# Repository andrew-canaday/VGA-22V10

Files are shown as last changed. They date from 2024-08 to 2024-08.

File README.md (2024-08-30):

# 22V10 VGA Card

I had some ATF22V10C's lying around and tossed together a quick VGA card:

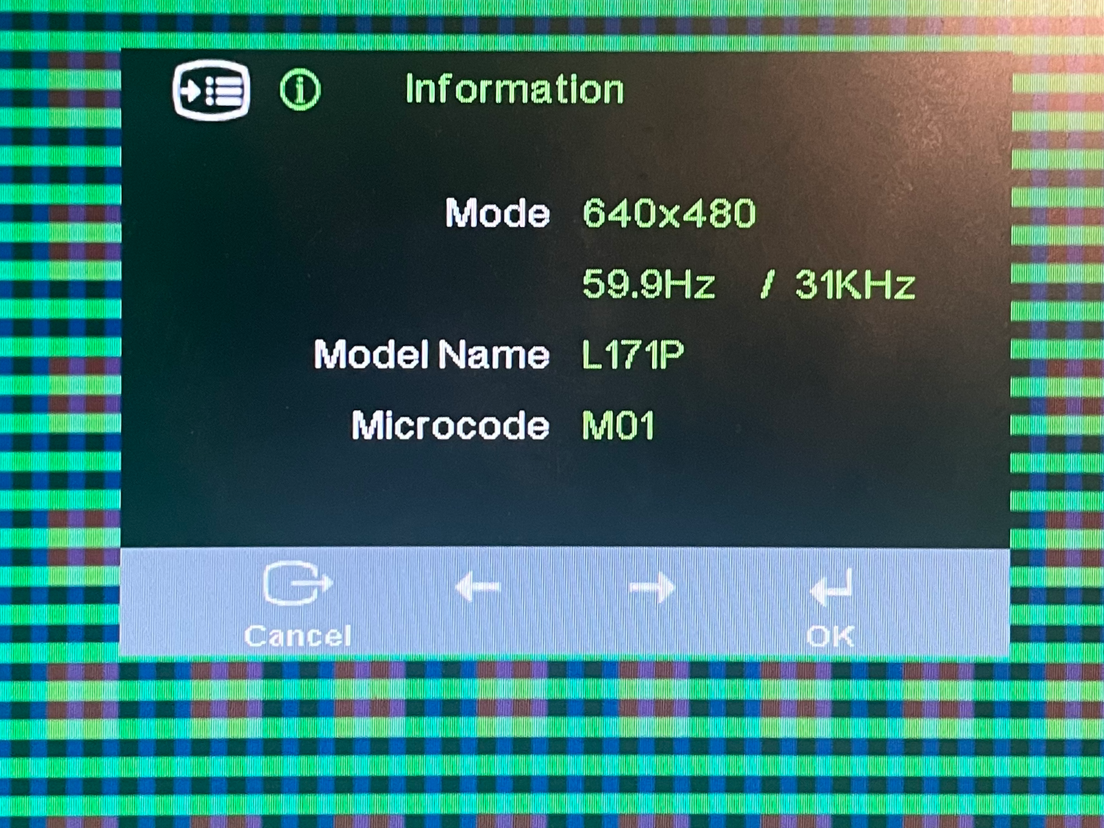
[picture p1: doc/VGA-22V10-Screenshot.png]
640x480 VGA Screenshot


### The Gist

> :information_source: **NOTE**: I happen to have a few **25.175MHz "Standard
> Clock" TCXO's and a pile of PLD's** lying around. Admittedly, this is a
> somewhat luxurious state of affairs. On the one hand, it makes the
> implementation significantly more straightforward. On the other, those aren't
> likely to be _super_ common "just lying around" parts for home hackers...

 - **Pixel Clock:** 25.175MHz
 - **Resolution:** 640x480
 - **Refresh:** 59.9Hz
 - 3 x ATF22V10C's
 - 1 x SN74**F**21 (Dual, 4-input, positive, `AND` — _mind your [Logic Family!](https://en.wikipedia.org/wiki/Logic_family#Monolithic_integrated_circuit_logic_families_compared)_)
 - **Inputs/Outputs:**
     - HSync + VSync,
     - "Visible" bool
     - VBlank flag
     - 20-bit pixel address output (10-bit H, 10-bit V)
     - analog RGB input

The POC is some pretty shoddy wire-pasta, but it works brilliantly...and is fun:

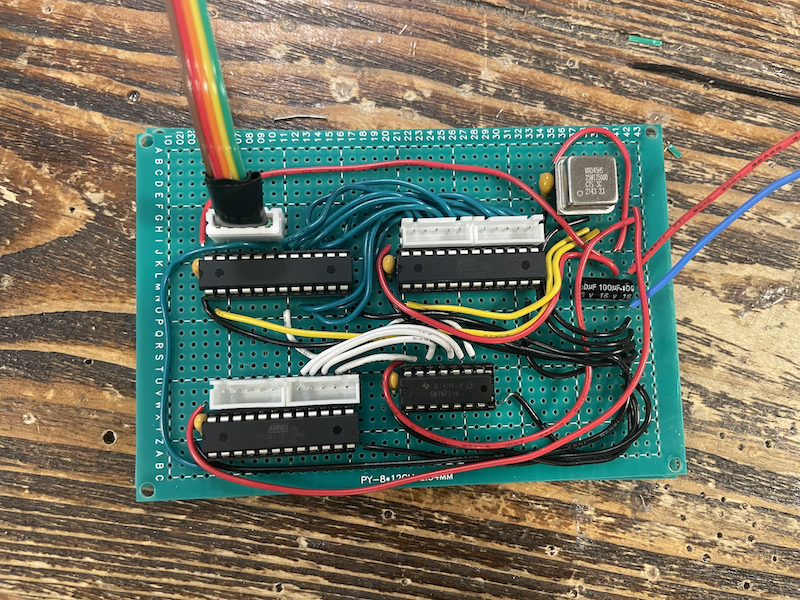
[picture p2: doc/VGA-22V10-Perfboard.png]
Gnarly, VGA, Perfboard Pasta


## Development

 - Written for GALasm (I use **[Galette](https://github.com/simon-frankau/galette)**)
 - Programmed with a T48 using **[Minipro](https://gitlab.com/DavidGriffith/minipro)**
 - For help: `make help`
 - To build and upload a unit: `UNIT=<my-file.pld> make clean compile upload`

### PLD Sources

> :information_source: **Schematic**: [PDF](./doc/schematic/22V10C-VGA-Card.pdf) / [SVG](./doc/schematic/22V10C-VGA-Card.svg)

 - `VGASync.pld` (ATF22V10C): HSync, VSync, Visible, and VBlank
 - `mod800.pld` (ATF22V10C): `% 800` counter
 - `mod525.pld` (ATF22V10C): `% 525` counter
 - Four-input `AND` on (`V32`, `V64`, `V128`, `V256`)

## Notes

 - I'm sure it's possible to reduce chip-count or make this more elegant — e.g. moving some of the sync
   counter logic from one IC into `VGASync.pld` / using some outputs in
   tri-state mode. This isn't the _optimal_ solution; it's just an easy,
   off-the-cuff, solution with proper timing.
 - Pinouts: _these are malleable!_ The current disposition is informed, more than
   anything else, by where the IC's happened to land on my breadboard.
   **Just mind your product terms!** (The number of product terms available to each
   macrocell varies by pin).
 - If you don't have "spare" 22V10's, you can replace the mod800/mod525 counters
   with synchronous counters or ripple-counters + latches. If you spec out your
   parts, mind your gate delays, and maybe add some additional product terms
   to your equations, you might be able to get away with a couple of 10+ bit
   ripple counters too!

## Misc

### Other PLD files

 - `counter.pld`: Generic 10-bit synchronous counter.
 - `eq-9-bit.pld`: Bit-wise comparison, 9-bits.

### Fun

#### Analog Switch Pixel Gate

Use the `Visible` output of `VGASync` to toggle 3 x SPST or SPDT switches for
red, green, and blue.

> :warning: **NOTE**: Watch your propagation delays!
>    
> If you use an analog switch that has a large ON/OFF (or Inhibit)
> propagation delay, relative to the pixel clock, you'll want to turn it
> on and off <i>early</i> to avoid offsetting your pixels horizontally.

#### Boolean Grids

Have some fast CMOS or TTL logic gates lying around? Taking the output from one
or more bits from `VAddr` and `HAddr`, passing them through some gates, and
`AND`'ing them with the `Visible` flag is a great way to check your pixel
alignment (this is how the grid pattern in the screenshot above was generated).

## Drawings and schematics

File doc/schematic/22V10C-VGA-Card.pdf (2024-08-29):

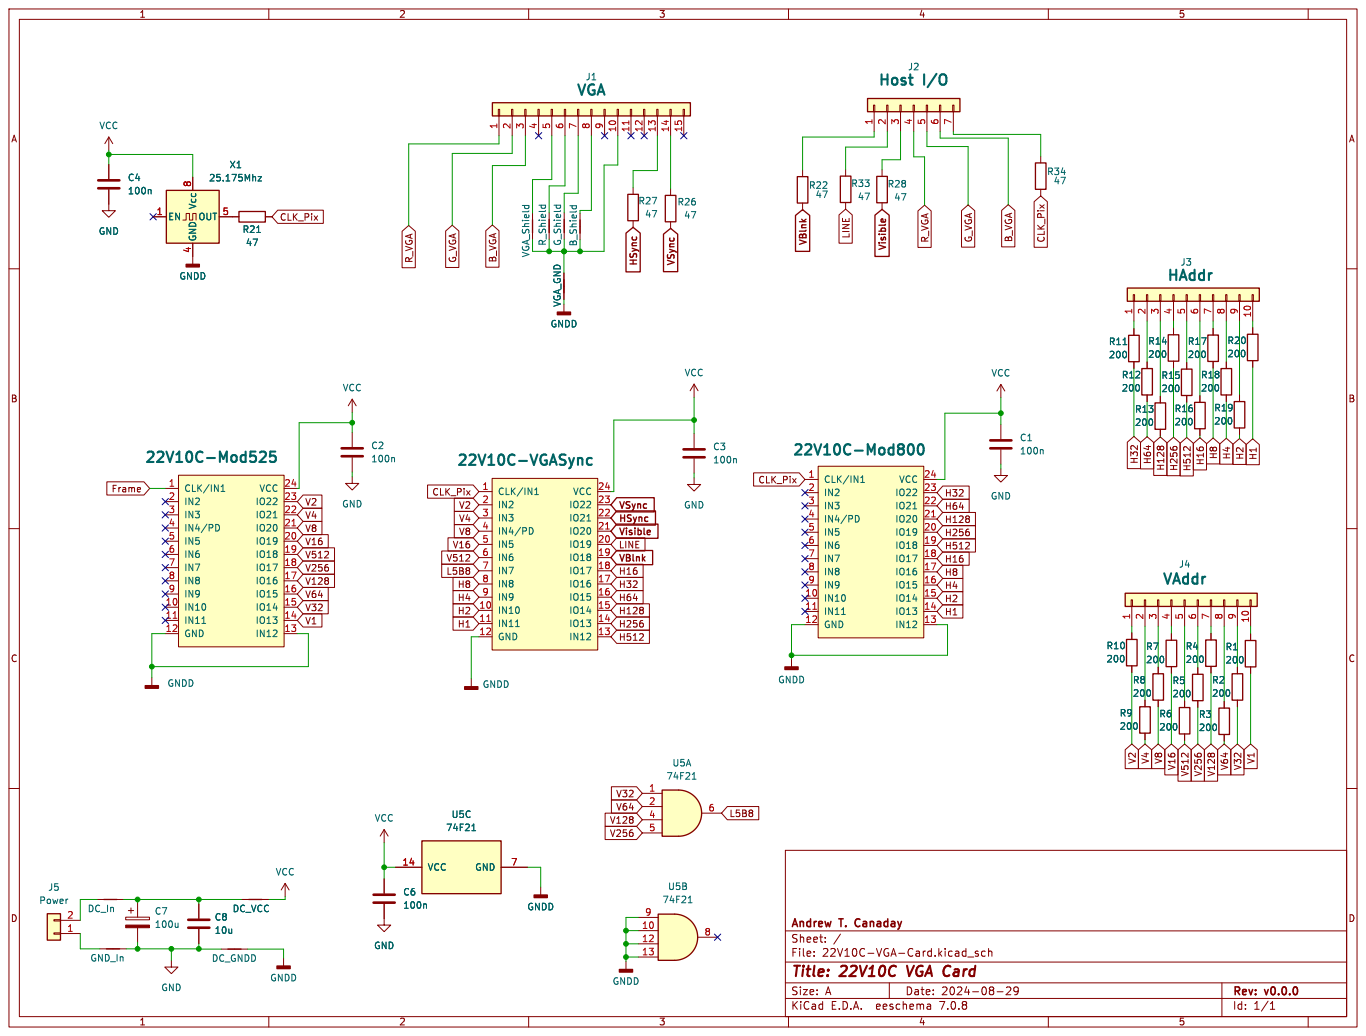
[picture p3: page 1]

Id: 1/1 Title: 22V10C VGA Card

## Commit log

2024-08-29 HACK HACK HACK: 640x480 VGA driver
2024-08-29 Schematic: fix net labels.
2024-08-29 Schematic: WHOOPS. Update net labels to reflect PLD files...
2024-08-30 doc: add PLD pinouts + KiCAD schematic...in case there are other disparities and someone wants to PR.
    [22V10C-VGA-Card.kicad_sch]
2024-08-30 doc: shuffle schematic files into subdir.
2024-08-31 ...remove KiCAD lock file.
